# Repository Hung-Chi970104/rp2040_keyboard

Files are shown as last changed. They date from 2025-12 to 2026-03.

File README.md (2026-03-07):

# Full-size keyboard with integrated RP2040 chip
A keyboard that’s actually a computer! Inspired by from Raspberry Pi 500, but instead with a powerful RP2040 inside, you can code as you type, like run Python, compile C/C++, and literally type programs on the go!
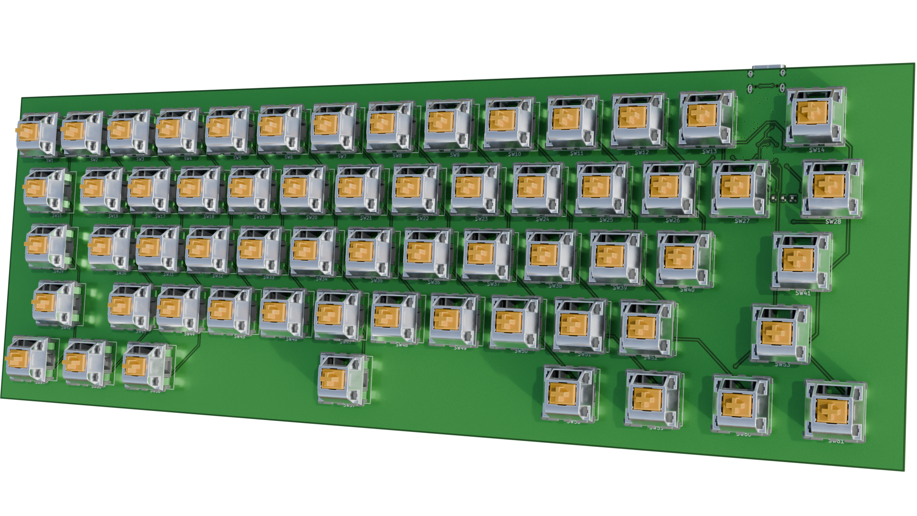
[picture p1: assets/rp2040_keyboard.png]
Assembled


## Components
- RP2040
- 12MHz Crystal (ABM8-272-T3)
- 2MB Flash Storage (W25Q16JVUXIQ)
- Buck-Boost Switching Regulator (RT6154AGQW)
- USB-C (TYPE-C-31-M-12)

## Designs
schematic_MCU
schematic_map
pcb_B
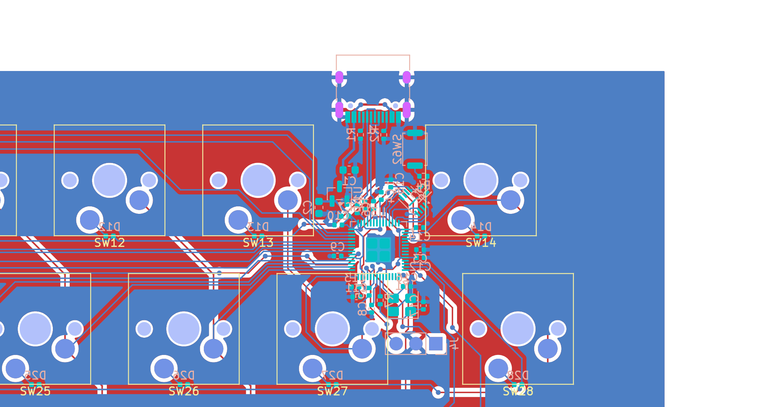
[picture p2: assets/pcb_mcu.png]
pcb_mcu

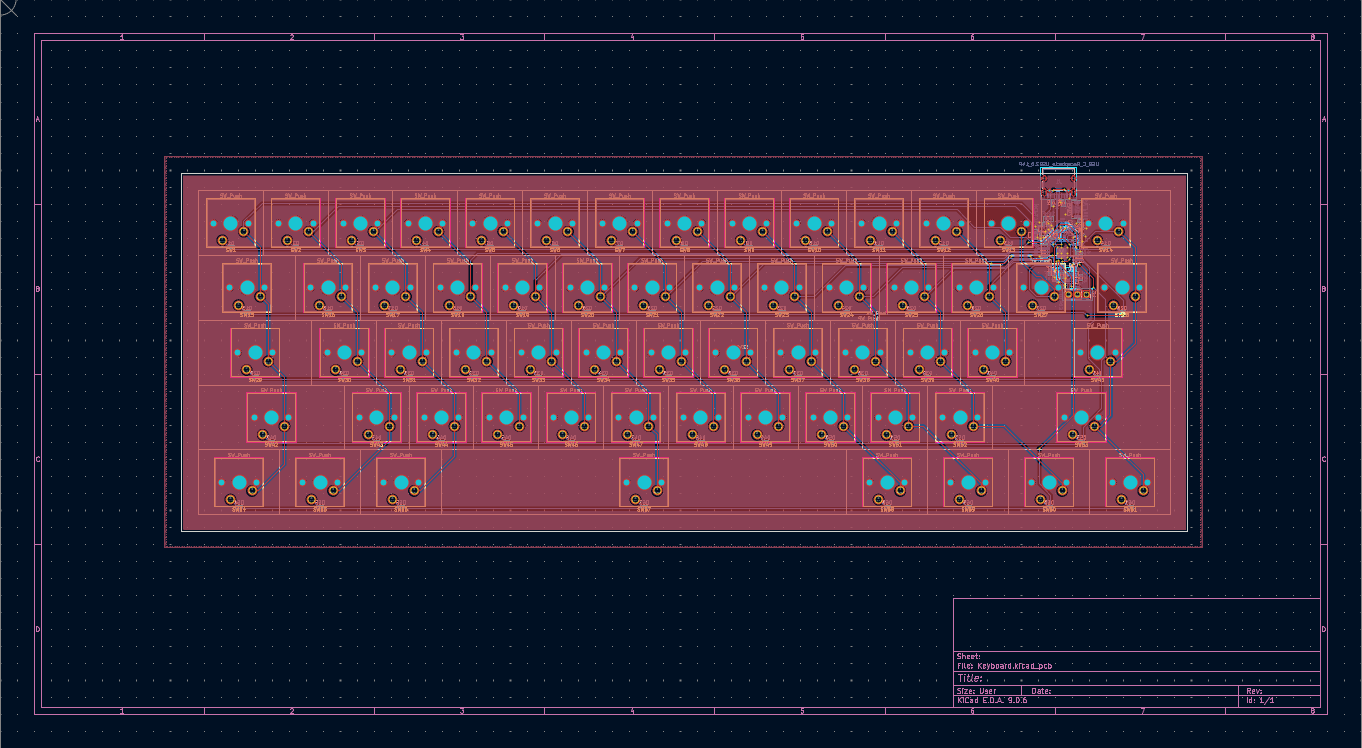
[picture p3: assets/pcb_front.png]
pcb_front

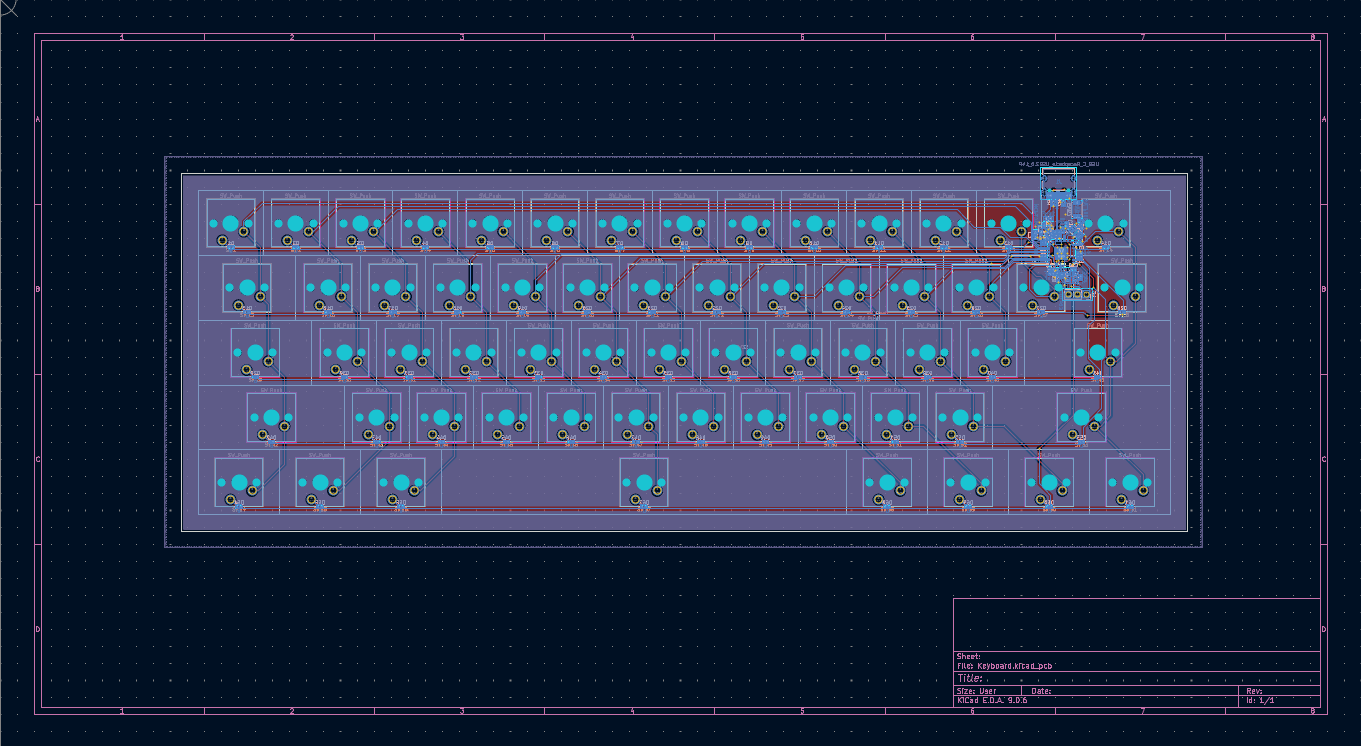
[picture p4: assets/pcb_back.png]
pcb_back

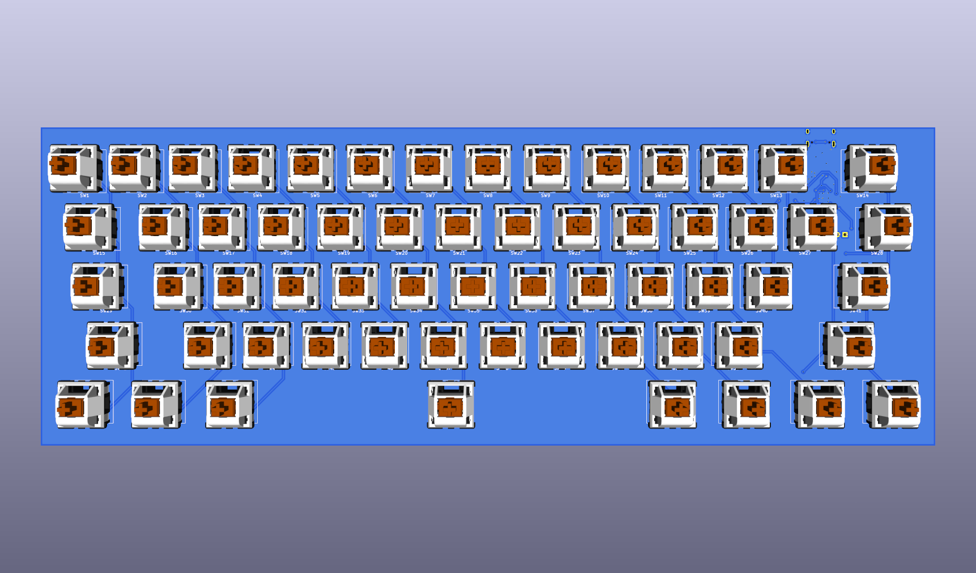
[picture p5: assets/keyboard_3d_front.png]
keyboard_3d_front

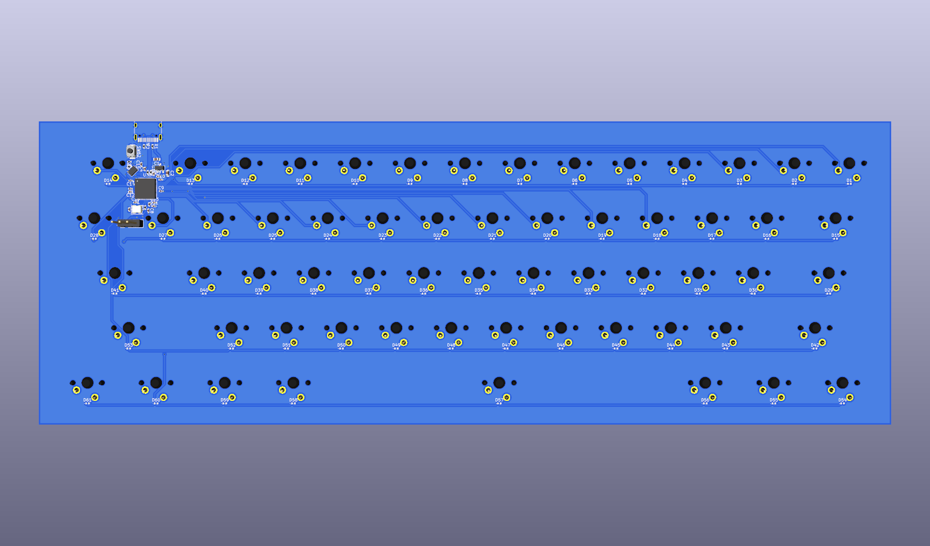
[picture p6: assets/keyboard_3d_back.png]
keyboard_3d_back


## Conclusion
I gotta be honest working on this wasn't as easy as I thought, mainly beacuse of new layout for RP2040 and my poor planning (yeah that's my problem).......But anyways I'll order this right after I get my RP2040 devboard that I built previously just in case I made some stupid mistakes lol

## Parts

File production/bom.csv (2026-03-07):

Designator | Footprint | Quantity | Value | LCSC Part #
C1, C2 | 0603 | 2 | 10uF
C10, C11, C12, C13, C14, C15, C3, C5, C6, C8, C9 | 0402 | 11 | 0.1uF
C16, C17 | 0402 | 2 | 33pF
C4, C7 | 0402 | 2 | 1uF
D1, D10, D11, D12, D13, D14, D15, D16, D17, D18, D19, D2, D20, D21, D22, D23, D24, D25, D26, D27, D28, D29, D3, D30, D31, D32, D33, D34, D35, D36, D37, D38, D39, D4, D40, D41, D42, D43, D44, D45, D46, D47, D48, D49, D5, D50, D51, D52, D53, D54, D55, D56, D57, D58, D59, D6, D60, D61, D7, D8, D9 | 0402 | 61 | D
J1 | USB_C_Receptacle_HRO_TYPE-C-31-M-12 | 1 | USB_C_Receptacle_USB2.0_14P
J4 | PinHeader_1x03_P2.54mm_Vertical | 1 | Conn_01x03
R1, R2 | 0402 | 2 | 5.1K
R3 | 0402 | 1 | 10K
R4, R7 | 0402 | 2 | 1K
R5, R6 | 0402 | 2 | 27
SW1, SW10, SW11, SW12, SW13, SW16, SW17, SW18, SW19, SW2, SW20, SW21, SW22, SW23, SW24, SW25, SW26, SW27, SW3, SW30, SW31, SW32, SW33, SW34, SW35, SW36, SW37, SW38, SW39, SW4, SW40, SW43, SW44, SW45, SW46, SW47, SW48, SW49, SW5, SW50, SW51, SW52, SW6, SW7, SW8, SW9 | SW_Cherry_MX_PCB_1.00u | 46 | SW_Push
SW14 | SW_Cherry_MX_PCB_2.00u | 1 | SW_Push
SW15, SW28 | SW_Cherry_MX_PCB_1.50u | 2 | SW_Push
SW29 | SW_Cherry_MX_PCB_1.75u | 1 | SW_Push
SW41, SW42 | SW_Cherry_MX_PCB_2.25u | 2 | SW_Push
SW53 | SW_Cherry_MX_PCB_2.75u | 1 | SW_Push
SW54, SW55, SW56, SW58, SW59, SW60, SW61 | SW_Cherry_MX_PCB_1.25u | 7 | SW_Push
SW57 | SW_Cherry_MX_PCB_6.25u | 1 | SW_Push
SW62 | SW_Push_SPST_NO_Alps_SKRK | 1 | SW_Push
U1 | SOT-23 | 1 | MCP1700x-330xxTT
U2 | Winbond_USON-8-1EP_3x2mm_P0.5mm_EP0.2x1.6mm | 1 | W25Q16JVUXIQ TR
U3 | QFN-56-1EP_7x7mm_P0.4mm_EP3.2x3.2mm | 1 | RP2040
Y1 | Crystal_SMD_3225-4Pin_3.2x2.5mm | 1 | 12 MHz

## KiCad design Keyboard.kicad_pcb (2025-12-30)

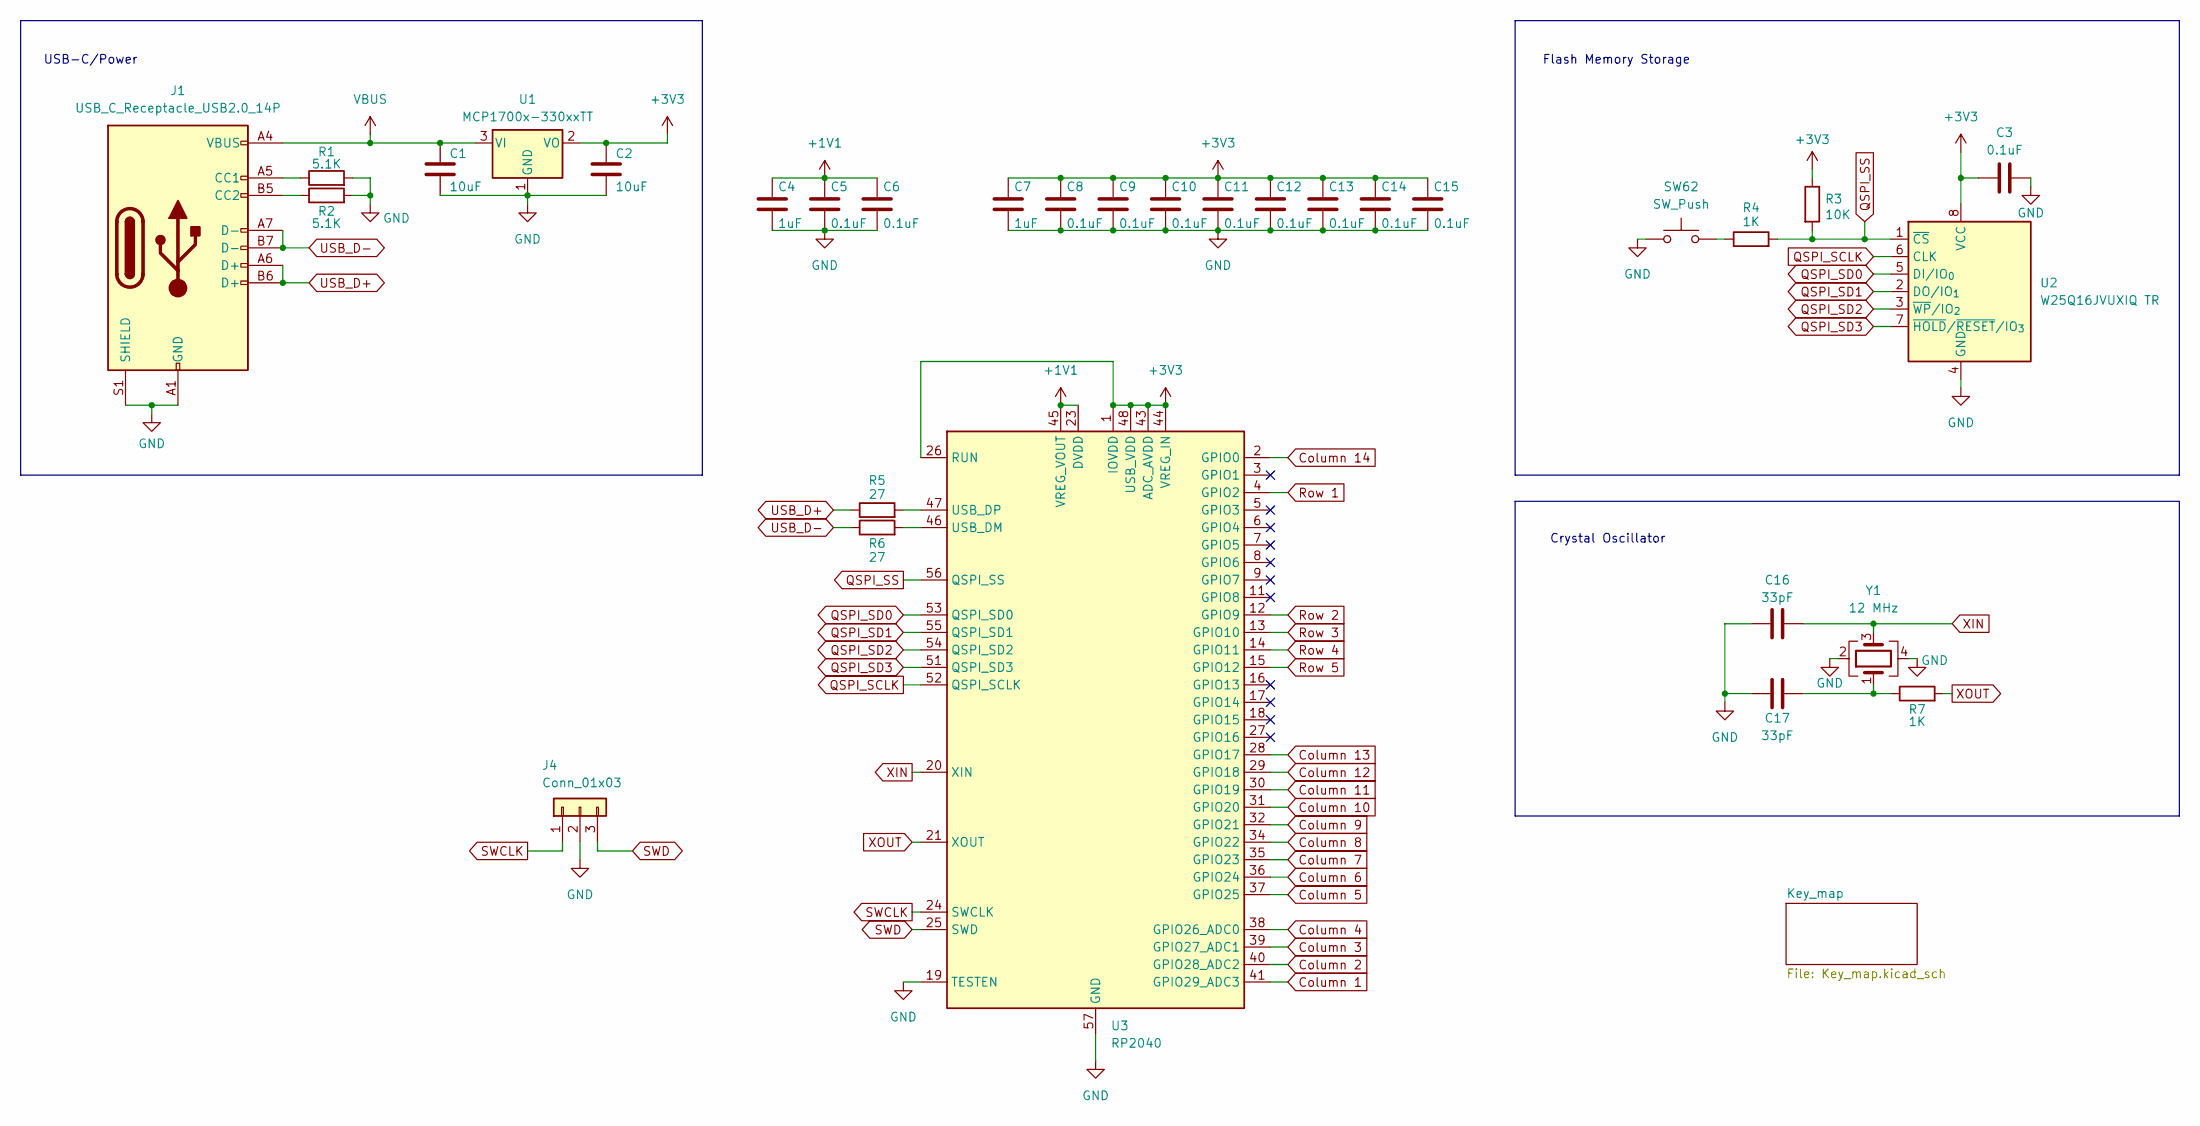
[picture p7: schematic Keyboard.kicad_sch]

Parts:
C1, C2: 10uF; C_0603_1608Metric
C3, C5, C6, C8, C9, C10, C11, C12, C13, C14, C15: 0.1uF; C_0402_1005Metric
C4, C7: 1uF; C_0402_1005Metric
C16, C17: 33pF; C_0402_1005Metric
J1: USB_C_Receptacle_USB2.0_14P; USB_C_Receptacle_HRO_TYPE-C-31-M-12
J4: Conn_01x03; PinHeader_1x03_P2.54mm_Vertical
R1, R2: 5.1K; R_0402_1005Metric
R3: 10K; R_0402_1005Metric
R4, R7: 1K; R_0402_1005Metric
R5, R6: 27; R_0402_1005Metric
SW62: SW_Push; SW_Push_SPST_NO_Alps_SKRK
U1: MCP1700x-330xxTT; SOT-23
U2: W25Q16JVUXIQ TR; Winbond_USON-8-1EP_3x2mm_P0.5mm_EP0.2x1.6mm
U3: RP2040; QFN-56-1EP_7x7mm_P0.4mm_EP3.2x3.2mm
Y1: 12 MHz; Crystal_SMD_3225-4Pin_3.2x2.5mm

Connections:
+1V1: C4.1, C5.1, C6.1, U3.23 (DVDD), U3.45 (VREG_VOUT), U3.50 (DVDD)
+3V3: C2.1, C3.1, C7.1, C8.1, C9.1, C10.1, C11.1, C12.1, C13.1, C14.1, C15.1, R3.1, U1.2 (VO), U2.8 (VCC), U3.1 (IOVDD), U3.10 (IOVDD), U3.22 (IOVDD), U3.26 (RUN), U3.33 (IOVDD), U3.42 (IOVDD), U3.43 (ADC_AVDD), U3.44 (VREG_IN), U3.48 (USB_VDD), U3.49 (IOVDD)
Column 1: U3.41 (GPIO29_ADC3); also elsewhere on the board
Column 2: U3.40 (GPIO28_ADC2); also elsewhere on the board
Column 3: U3.39 (GPIO27_ADC1); also elsewhere on the board
Column 4: U3.38 (GPIO26_ADC0); also elsewhere on the board
Column 5: U3.37 (GPIO25); also elsewhere on the board
Column 6: U3.36 (GPIO24); also elsewhere on the board
Column 7: U3.35 (GPIO23); also elsewhere on the board
Column 8: U3.34 (GPIO22); also elsewhere on the board
Column 9: U3.32 (GPIO21); also elsewhere on the board
Column 10: U3.31 (GPIO20); also elsewhere on the board
Column 11: U3.30 (GPIO19); also elsewhere on the board
Column 12: U3.29 (GPIO18); also elsewhere on the board
Column 13: U3.28 (GPIO17); also elsewhere on the board
Column 14: U3.2 (GPIO0); also elsewhere on the board
GND: C1.2, C2.2, C3.2, C4.2, C5.2, C6.2, C7.2, C8.2, C9.2, C10.2, C11.2, C12.2, C13.2, C14.2, C15.2, C16.1, C17.1, J1.A1 (GND), J1.A12 (GND), J1.B1 (GND), J1.B12 (GND), J1.S1 (SHIELD), J4.2, R1.2, R2.2, SW62.1, U1.1 (GND), U2.4 (GND), U3.19 (TESTEN), U3.57 (GND), Y1.2, Y1.4
unnamed: C17.2, R7.1, Y1.1
unnamed: J1.A5 (CC1), R1.1
unnamed: J1.B5 (CC2), R2.1
unnamed: R4.1, SW62.2
unnamed: R6.2, U3.46 (USB_DM)
unnamed: R5.2, U3.47 (USB_DP)
QSPI_SCLK: U2.6 (CLK), U3.52 (QSPI_SCLK)
QSPI_SD0: U2.5 (DI/IO_{0}), U3.53 (QSPI_SD0)
QSPI_SD1: U2.2 (DO/IO_{1}), U3.55 (QSPI_SD1)
QSPI_SD2: U2.3 (~WP/IO_{2}), U3.54 (QSPI_SD2)
QSPI_SD3: U2.7 (~HOLD/~RESET/IO_{3}), U3.51 (QSPI_SD3)
QSPI_SS: R3.2, R4.2, U2.1 (~CS), U3.56 (QSPI_SS)
Row 1: U3.4 (GPIO2); also elsewhere on the board
Row 2: U3.12 (GPIO9); also elsewhere on the board
Row 3: U3.13 (GPIO10); also elsewhere on the board
Row 4: U3.14 (GPIO11); also elsewhere on the board
Row 5: U3.15 (GPIO12); also elsewhere on the board
SWCLK: J4.1, U3.24 (SWCLK)
SWD: J4.3, U3.25 (SWD)
USB_D+: J1.A6 (D+), J1.B6 (D+), R5.1
USB_D-: J1.A7 (D-), J1.B7 (D-), R6.1
VBUS: C1.1, J1.A4 (VBUS), J1.A9 (VBUS), J1.B4 (VBUS), J1.B9 (VBUS), U1.3 (VI)
XIN: C16.2, U3.20 (XIN), Y1.3
XOUT: R7.2, U3.21 (XOUT)

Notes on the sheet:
Crystal Oscillator
Flash Memory Storage
USB-C/Power

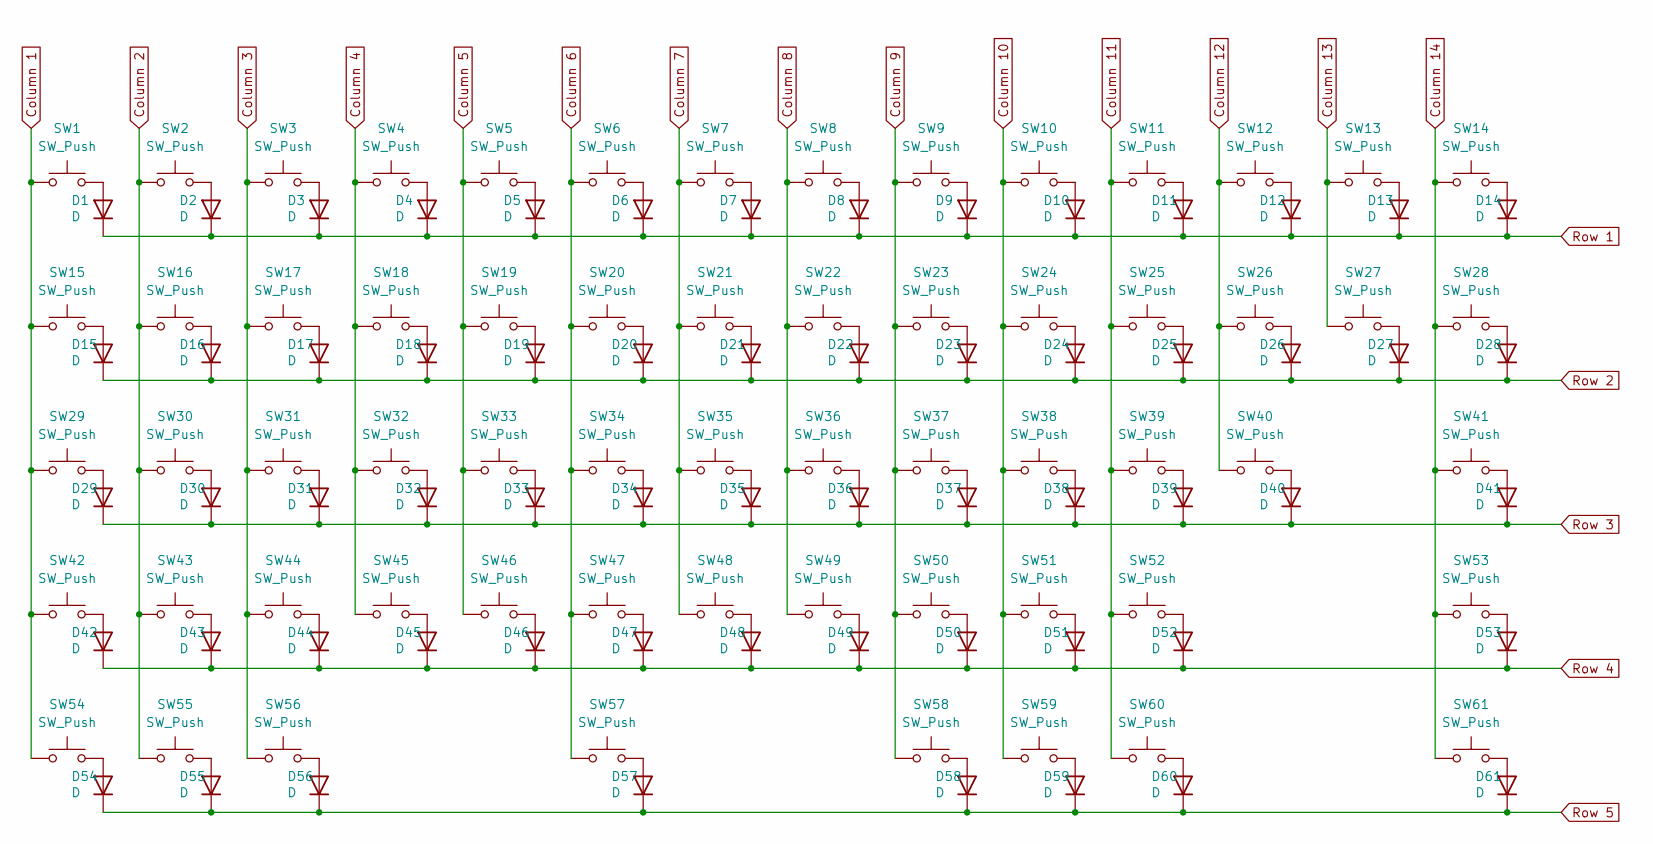
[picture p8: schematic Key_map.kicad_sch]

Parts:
D1, D2, D3, D4, D5, D6, D7, D8, D9, D10, D11, D12, D13, D14, D15, D16, D17, D18, D19, D20, D21, D22, D23, D24, D25, D26, D27, D28, D29, D30, D31, D32, D33, D34, D35, D36, D37, D38, D39, D40, D41, D42, D43, D44, D45, D46, D47, D48, D49, D50, D51, D52, D53, D54, D55, D56, D57, D58, D59, D60, D61: D; D_0402_1005Metric
SW1, SW2, SW3, SW4, SW5, SW6, SW7, SW8, SW9, SW10, SW11, SW12, SW13, SW16, SW17, SW18, SW19, SW20, SW21, SW22, SW23, SW24, SW25, SW26, SW27, SW30, SW31, SW32, SW33, SW34, SW35, SW36, SW37, SW38, SW39, SW40, SW43, SW44, SW45, SW46, SW47, SW48, SW49, SW50, SW51, SW52: SW_Push; SW_Cherry_MX_PCB_1.00u
SW14: SW_Push; SW_Cherry_MX_PCB_2.00u
SW15, SW28: SW_Push; SW_Cherry_MX_PCB_1.50u
SW29: SW_Push; SW_Cherry_MX_PCB_1.75u
SW41, SW42: SW_Push; SW_Cherry_MX_PCB_2.25u
SW53: SW_Push; SW_Cherry_MX_PCB_2.75u
SW54, SW55, SW56, SW58, SW59, SW60, SW61: SW_Push; SW_Cherry_MX_PCB_1.25u
SW57: SW_Push; SW_Cherry_MX_PCB_6.25u

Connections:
Column 1: SW1.1, SW15.1, SW29.1, SW42.1, SW54.1; also elsewhere on the board
Column 2: SW2.1, SW16.1, SW30.1, SW43.1, SW55.1; also elsewhere on the board
Column 3: SW3.1, SW17.1, SW31.1, SW44.1, SW56.1; also elsewhere on the board
Column 4: SW4.1, SW18.1, SW32.1, SW45.1; also elsewhere on the board
Column 5: SW5.1, SW19.1, SW33.1, SW46.1; also elsewhere on the board
Column 6: SW6.1, SW20.1, SW34.1, SW47.1, SW57.1; also elsewhere on the board
Column 7: SW7.1, SW21.1, SW35.1, SW48.1; also elsewhere on the board
Column 8: SW8.1, SW22.1, SW36.1, SW49.1; also elsewhere on the board
Column 9: SW9.1, SW23.1, SW37.1, SW50.1, SW58.1; also elsewhere on the board
Column 10: SW10.1, SW24.1, SW38.1, SW51.1, SW59.1; also elsewhere on the board
Column 11: SW11.1, SW25.1, SW39.1, SW52.1, SW60.1; also elsewhere on the board
Column 12: SW12.1, SW26.1, SW40.1; also elsewhere on the board
Column 13: SW13.1, SW27.1; also elsewhere on the board
Column 14: SW14.1, SW28.1, SW41.1, SW53.1, SW61.1; also elsewhere on the board
unnamed: D1.2 (A), SW1.2
unnamed: D2.2 (A), SW2.2
unnamed: D3.2 (A), SW3.2
unnamed: D4.2 (A), SW4.2
unnamed: D5.2 (A), SW5.2
unnamed: D6.2 (A), SW6.2
unnamed: D7.2 (A), SW7.2
unnamed: D8.2 (A), SW8.2
unnamed: D9.2 (A), SW9.2
unnamed: D10.2 (A), SW10.2
unnamed: D11.2 (A), SW11.2
unnamed: D12.2 (A), SW12.2
unnamed: D13.2 (A), SW13.2
unnamed: D14.2 (A), SW14.2
unnamed: D15.2 (A), SW15.2
unnamed: D16.2 (A), SW16.2
unnamed: D17.2 (A), SW17.2
unnamed: D18.2 (A), SW18.2
unnamed: D19.2 (A), SW19.2
unnamed: D20.2 (A), SW20.2
unnamed: D21.2 (A), SW21.2
unnamed: D22.2 (A), SW22.2
unnamed: D23.2 (A), SW23.2
unnamed: D24.2 (A), SW24.2
unnamed: D25.2 (A), SW25.2
unnamed: D26.2 (A), SW26.2
unnamed: D27.2 (A), SW27.2
unnamed: D28.2 (A), SW28.2
unnamed: D29.2 (A), SW29.2
unnamed: D30.2 (A), SW30.2
unnamed: D31.2 (A), SW31.2
unnamed: D32.2 (A), SW32.2
unnamed: D33.2 (A), SW33.2
unnamed: D34.2 (A), SW34.2
unnamed: D35.2 (A), SW35.2
unnamed: D36.2 (A), SW36.2
unnamed: D37.2 (A), SW37.2
unnamed: D38.2 (A), SW38.2
unnamed: D39.2 (A), SW39.2
unnamed: D40.2 (A), SW40.2
unnamed: D41.2 (A), SW41.2
unnamed: D42.2 (A), SW42.2
unnamed: D43.2 (A), SW43.2
unnamed: D44.2 (A), SW44.2
unnamed: D45.2 (A), SW45.2
unnamed: D46.2 (A), SW46.2
unnamed: D47.2 (A), SW47.2
unnamed: D48.2 (A), SW48.2
unnamed: D49.2 (A), SW49.2
unnamed: D50.2 (A), SW50.2
unnamed: D51.2 (A), SW51.2
unnamed: D52.2 (A), SW52.2
unnamed: D53.2 (A), SW53.2
unnamed: D54.2 (A), SW54.2
unnamed: D55.2 (A), SW55.2
unnamed: D56.2 (A), SW56.2
unnamed: D57.2 (A), SW57.2
unnamed: D58.2 (A), SW58.2
unnamed: D59.2 (A), SW59.2
unnamed: D60.2 (A), SW60.2
unnamed: D61.2 (A), SW61.2
Row 1: D1.1 (K), D2.1 (K), D3.1 (K), D4.1 (K), D5.1 (K), D6.1 (K), D7.1 (K), D8.1 (K), D9.1 (K), D10.1 (K), D11.1 (K), D12.1 (K), D13.1 (K), D14.1 (K); also elsewhere on the board
Row 2: D15.1 (K), D16.1 (K), D17.1 (K), D18.1 (K), D19.1 (K), D20.1 (K), D21.1 (K), D22.1 (K), D23.1 (K), D24.1 (K), D25.1 (K), D26.1 (K), D27.1 (K), D28.1 (K); also elsewhere on the board
Row 3: D29.1 (K), D30.1 (K), D31.1 (K), D32.1 (K), D33.1 (K), D34.1 (K), D35.1 (K), D36.1 (K), D37.1 (K), D38.1 (K), D39.1 (K), D40.1 (K), D41.1 (K); also elsewhere on the board
Row 4: D42.1 (K), D43.1 (K), D44.1 (K), D45.1 (K), D46.1 (K), D47.1 (K), D48.1 (K), D49.1 (K), D50.1 (K), D51.1 (K), D52.1 (K), D53.1 (K); also elsewhere on the board
Row 5: D54.1 (K), D55.1 (K), D56.1 (K), D57.1 (K), D58.1 (K), D59.1 (K), D60.1 (K), D61.1 (K); also elsewhere on the board

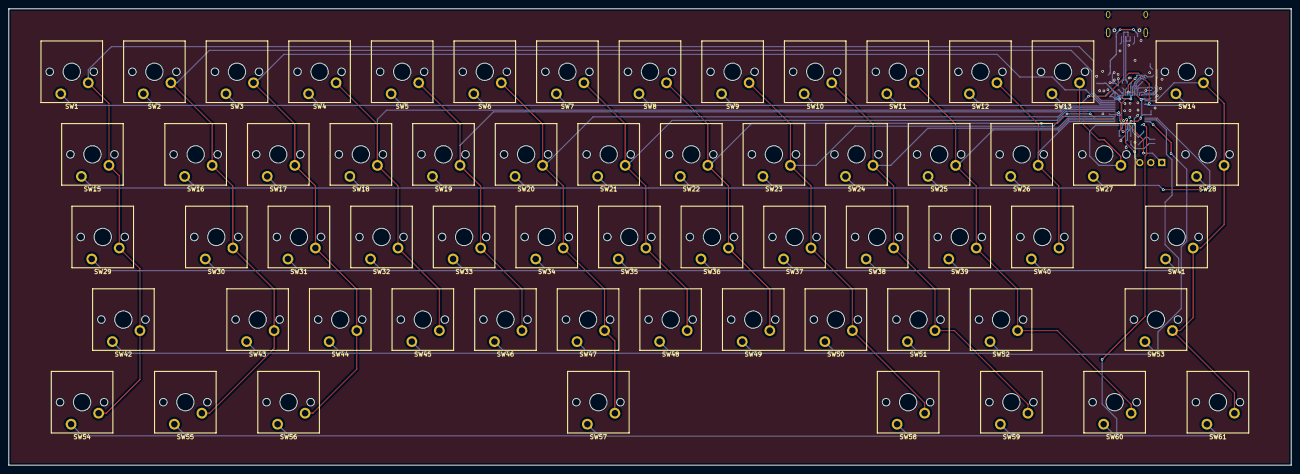
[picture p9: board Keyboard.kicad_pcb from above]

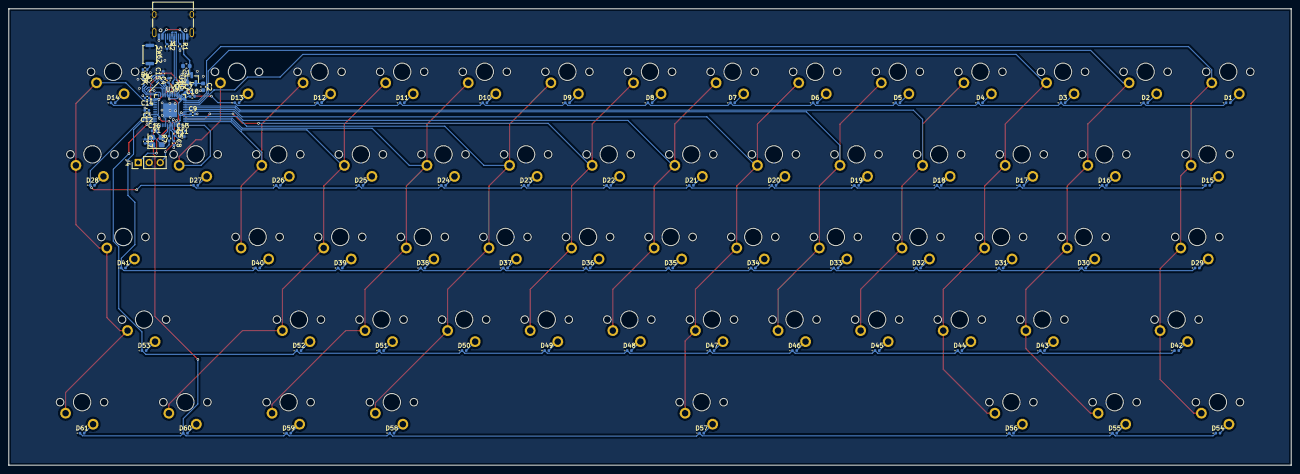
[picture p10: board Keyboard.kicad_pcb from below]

Board: 2 copper layers, 295.8 x 105.2 mm, 153 parts (92 on the bottom side), 102 nets.
